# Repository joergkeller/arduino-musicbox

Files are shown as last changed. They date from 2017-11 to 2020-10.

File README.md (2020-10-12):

# Arduino MusicBox

Arduino control code for a music maker board and a trellis keypad with optional nfc reader.

Hardware parts:
* Adafruit Feather 32u4 Basic Proto
* Adafruit FeatherWing MusicMaker
* Adafruit Trellis PCB, Elastomer, LED
* PN532 NFC reader
* Amplifier, Stereo speaker 
* Rotary Decoder
* LiPolymer 3.7V Akku

The control code shall
* animate the trellis keys while idle
* read trellis keys
* on key press play a music track from the micro SD card from a configured folder and blink the respective key
* on pressing the same key or when playback stops jump to the next track in the folder, until all music is played
* read the rotary decoder to change the volume, the maximum volume can be configured
* press the rotary decoder to pause/resume (short) and stop/sleep (long)
* detect when a headphone is plugged in and mute the amplifier for the internal speakers
* read nfc chips and play the configured track or album for the given id
* switch the music box  off automatically after an idle period

## Checkout this code
```
git clone https://github.com/joergkeller/arduino-musicbox.git
cd arduino-musicbox
git submodule init
git submodule update
```

## Remarks on the hardware
* See [wiring schema](extras/schema/MusicBox_Schaltplan.pdf)
* Cut the "RESET" bridge on the Adafruit MusicMaker FeatherWing (otherwise a reset of the mp3 chip will also 
  reset the arduino board).
* Set dip switches on the NFC board to use I2C (1: ON, 2: OFF)

## Prepare micro SD card
Copy \<musicbox\>/extras/config/*.cfg in root directory of the SD card.\
Copy music files to the SD card, using 8.3 filenames without special characters.
Assign paths to buttons in buttons.cfg and NFC ids in nfc.cfg.\
Paths can be a folder (all tracks will be played) or a specific story/song. Music files can be in subfolders, but
deeply nested structures should be avoided.

## Howto install using Arduino IDE

File > Preferences > Sketchbook locations:\
\<musicbox\> folder containing src, libraries, extra folders

File > Preferences > Additional Boards Manager URLs:\
https://adafruit.github.io/arduino-board-index/package_adafruit_index.json

Tools > Board > Boards Manager\
 Install Adafruit AVR Boards

Restart Arduino IDE\
Open \<musicbox\>/src/src.ino

Tools > Boards\
 Adafruit Feather 32u4

Tools > Ports\
\<USB port connected to the feather board\>

> Verify/Compile\
> Upload

## Howto install using Arduino CLI
```
arduino-cli core update-index
arduino-cli core install arduino:avr@1.8.3
arduino-cli core install adafruit:avr@1.4.13
arduino-cli compile src --fqbn=adafruit:avr:feather32u4
arduino-cli board list
arduino-cli upload src --fqbn=adafruit:avr:feather32u4 --port COM4 --verify --verbose
```

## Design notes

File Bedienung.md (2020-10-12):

# Bedienungsanleitung "Musikwürfel"

## Einschalten 

Der Musikwürfel kann entweder über den USB-micro Anschluss oder über den eingebauten Akku betrieben werden.
Im Akkubetrieb schaltet der Ein-/Ausschalter (nach vorne) das Gerät ein. Mit USB wird das Gerät mit Strom versorgt, sobald das Kabel eingesteckt ist.
Kurz nach dem Einschalten leuchten die 16 Tasten auf der Front in individuellen Farben auf. Das bedeutet, dass das Gerät bereit ist und die Musik ausgewählt werden kann.

Bemerkung: Je nach Konfiguration der Firmware leuchten die Fronttasten konstant, werden langsam auf-/abgeblendet oder wandern als Lauflicht.

## Musik wählen

Mit Druck auf eine der 16 Fronttasten kann das hinterlegte Musikstück bzw. das Album abgespielt werden. Bei einem Album kann durch erneuten Druck auf das nächste Stück gewechselt werden. Solange ein Musikstück spielt, blinkt die entsprechende Taste langsam.
Beim Abspielen eines Stücks kann durch eine beliebige Taste jederzeit auf das neue Album gewechselt werden.
Wenn ein Musikstück fertig ist, wird innerhalb eines Albums automatisch auf das nächste gewechselt. Nach dem letzten Stück eines Albums geht das Gerät in den Grundzustand (alle Tasten leuchten).

Falls einer Taste kein Musikstück/Album hinterlegt ist, geht das Gerät sofort wieder in den Grundzustand (alle Tasten leuchten).

Bemerkung: Innerhalb eines Albums kann nur vorwärts "geblättert" werden. Um wieder an den Anfang zu gelangen, muss man sich durch das ganze Album drücken, oder besser das Abspielen durch langes Drücken auf den Drehregler beenden und das Album erneut auswählen.

### Musik mit Figur auswählen

In der Konfiguration des Gerätes können NFC-Ids mit einem Musikstück bzw. Album verknüpft werden. Wenn eine Figur oder ein anderer Gegenstand mit einem entsprechenden NFC-Tag auf den Deckel des Musikwürfels gelegt wird, wird das entsprechende Stück abgespielt.

Bemerkung: Beim Abspielen eines Stücks über diese Funktion blinkt immer die erste Fronttaste. Bei einem Album kann mit der ersten Taste auf das nächste Musikstück gewechselt werden.

## Abspielen pausieren oder abbrechen

Durch kurzen Druck auf den Drehregler wird das aktuelle Stück pausiert. Das wird durch langsameres Blinken der aktuellen Fronttaste dargestellt. Ausserdem blinkt der Drehregler blau. Erneutes Drücken des Drehreglers spielt das Musikstück weiter ab.

Durch langer Druck auf den Drehregler (ca. 1 sek) wird das aktuelle Stück abgebrochen und das Gerät geht zurück in den Grundzustand (alle Tasten leuchten).

Bemerkung: Der Pausenzustand hat immer noch einen erhöhten Stromverbrauch, da der Musikdecoder immer läuft und das Musikstück geladen ist. Deshalb wird nach einer konfigurierbaren Zeit (aktuell 60 min) das Gerät in den Standby-Modus gesetzt, worauf eine Fortsetzung des Stücks nicht mehr möglich ist.

## Lautstärke regeln

Mit dem Drehregler kann die Lautstärke geregelt werden. Minimale und maximale Lautstärke können für Lautsprecher- und Kopfhörerbetrieb getrennt in der Konfiguration festgelegt werden.

Bemerkung: Wenn das Gerät ausgeschaltet oder in den Standby-Modus geht, wird die Lautstärke auf den initialen Wert zurückgesetzt.

## Gerät in Standby-Modus setzen

Im Grundmodus (alle Tasten leuchten) kann das Gerät durch langes Drücken (ca. 1 sek) auf den Drehregler in den Standby-Modus gesetzt werden. Nach einiger Zeit im Grundmodus (aktuell 15 min) schaltet sich das Gerät automatisch in den Standby-Modus. Hier werden alle Funktionen abgestellt und der Stromverbrauch wird reduziert. Im Standbymodus blinkt der Drehregler ca. alle 8 sek.

Das Abspielen eines Musikstücks wird ebenfalls durch langes Drücken (ca. 1 sek) gestoppt. Um nicht versehentlich die Funktion zu aktivieren, muss der Drehregler dann losgelassen und erneut lang gedrückt werden um in den Standby-Modus zu gelangen.

Durch Drücken einer beliebigen Fronttaste wird das Gerät wieder aktiviert und gelangt in den Grundmodus (alle Tasten leuchten). Dabei ist aber noch kein Album/Stück ausgewählt, dazu muss erneut eine der Fronttasten gedrückt werden.

## Akku aufladen

Um den Akku aufzuladen, muss das Gerät über einen USB-micro Anschluss mit Strom versorgt werden. *Achtung: Der Akku wird nur geladen, wenn das Gerät mit dem Hauptschalter eingeschalten ist!*

Es muss ein USB-micro Stecker mit einer langen Zunge verwendet werden um einen sicheren Kontakt zu gewährleisten.

Bemerkung: Der Ladestrom ist auf 100 mA begrenzt. Für einen grossen Akku (z.B. 2500 mAh) muss deshalb mit einer langen Ladezeit von z.B. 25 Std gerechnet werden.

## Musikstücke ablegen und verknüpfen

Dazu muss die MicroSD-Karte entnommen werden: Deckel auf der Rückseite entfernen, mit Finger auf die Karte *drücken* um sie zu entriegeln, dann entnehmen.

Die MicroSD kann direkt, über einen SD-Adapter oder ein Zusatzgerät gelesen/geschrieben werden.

- Musikstücke können in einem Verzeichnis als Album zusammengefasst und in beliebigen Unterverzeichnissen abgelegt sein.
- Alben/Musikstücke für die Tasten müssen in der Textdatei ```buttons.cfg``` festgelegt werden. 
- Alben/Musikstücke für Figuren mit NFC-Tags müssen mit ihrer NFC Id in der Textdatei ```nfc.cfg``` festgelegt werden.
- Die physische Reihenfolge der Musikstücke ist entscheidend, nicht die Sortierung nach Namen. Um das sicherzustellen, wird am besten ein Musikstück nach dem andern einzeln auf die SD-Karte geschrieben.
- Beim Einlesen eines neuen NFC-Tags wird die unbekannte Id in die Textdatei ```nfc.cfg``` geschrieben.

Bemerkung: In der aktuellen Version können nur max. 8 Zeichen pro Verzeichnis/Stück angegeben werden. Entweder wird der Name des Stücks auf 8 Zeichen gekürzt oder es wird der Kurzname des längeren Stücks ermittelt (Windows/Cmd mit ```dir /x```). Die Längenbeschränkung gilt auch für einzelne Verzeichnisnamen.

### Beispiel Konfigurationsfiles 
NFC Konfiguration ```nfc.cfg```:
```
6738BC0E=MIGROS/WICHTEL/ELI.MP3
B85D2D35=MIGROS/WICHTEL/FINN.MP3
```

Button Konfiguration ```buttons.cfg```:
```
3=GLOBI/FEUER
4=JAMADU
```

### Unterstützte Audio Decoder Formate

* MP3 CBR+VBR+ABR bis 320 kbps, 48 kHz
* Ogg Vorbis bis 48 kHz, 500 kbps
* AAC VBR, CBR bis 48 kHz, 576 kbps
* WMA (4.0/4.1/7/8/9) bis 48 kHz, 384 kbps
* FLAC bis 48 kHz, 24bit
* WAV (PCM, IMA_ADPCM, MPEGLAYER3)
* MIDI Format 0, max. Polyphonie 64

MP3 sollte ohne die Option 'joint stereo' kodiert werden.

MIDI Instrumente siehe [VS1053 Datenblatt](https://cdn-shop.adafruit.com/datasheets/vs1053.pdf) Seite 32

## Weitere Konfigurationen
- settings.cfg - wird im Moment nicht unterstützt

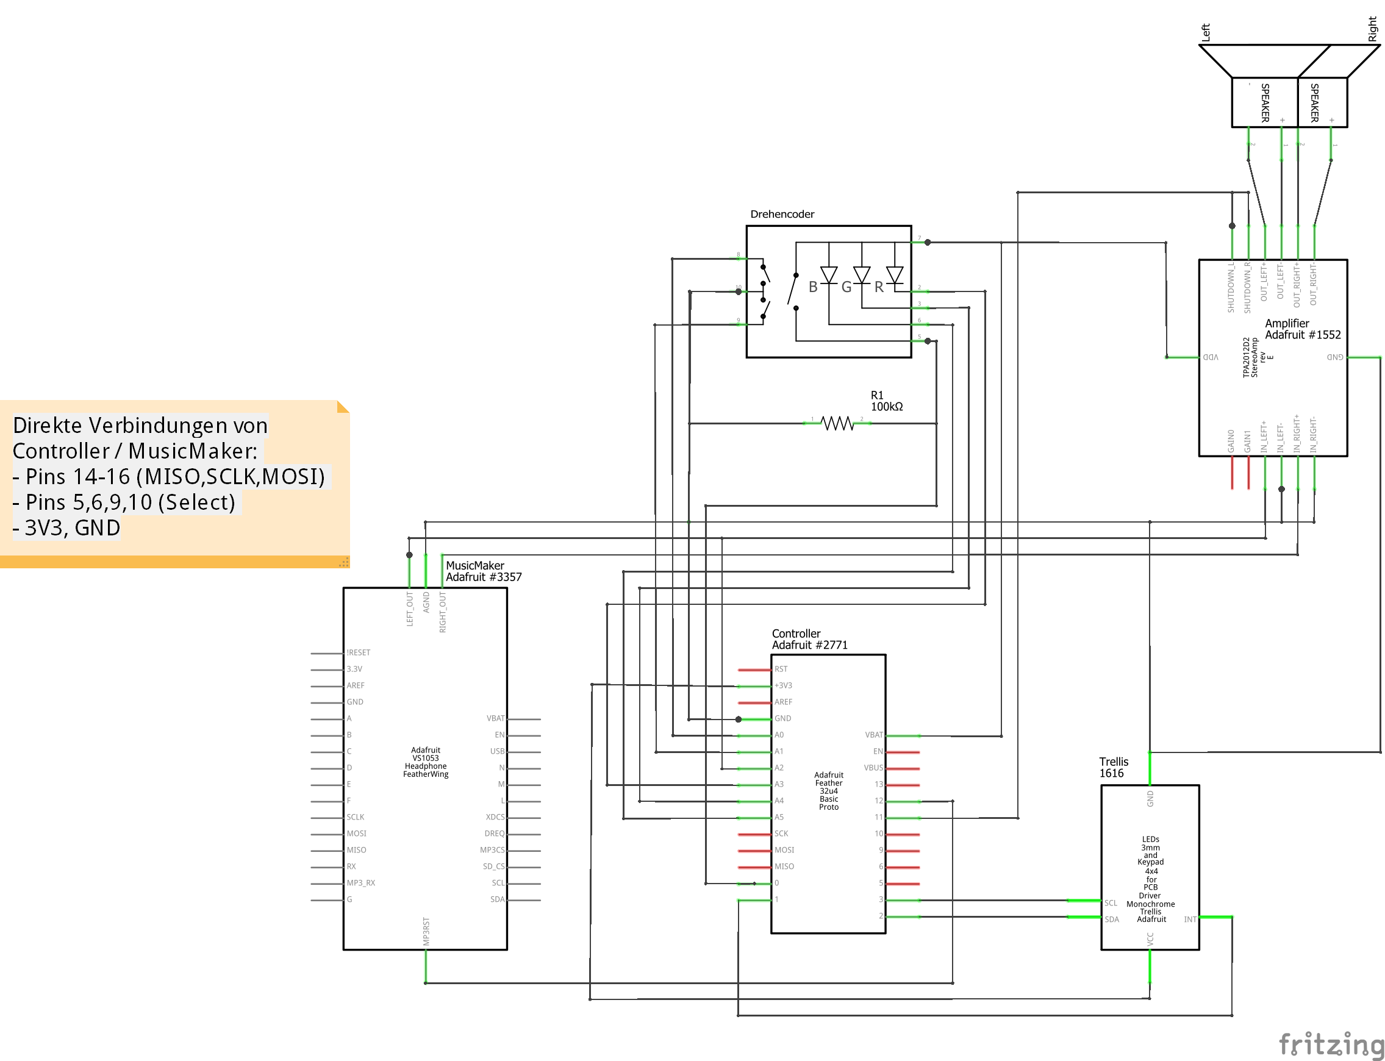
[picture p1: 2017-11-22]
extras/schema/MusicBox_Schaltplan.png

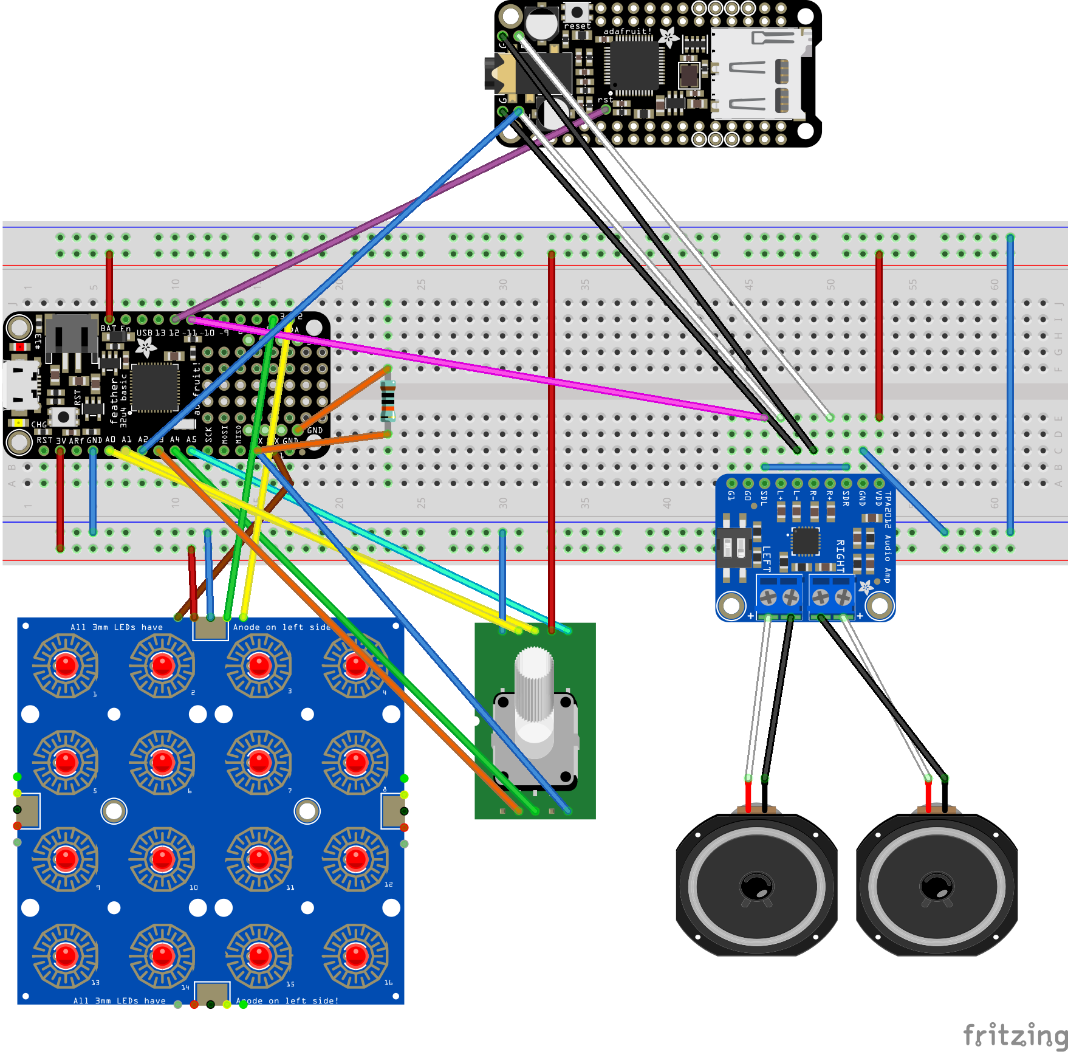
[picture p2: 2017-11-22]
extras/schema/MusicBox_Steckplatine.png

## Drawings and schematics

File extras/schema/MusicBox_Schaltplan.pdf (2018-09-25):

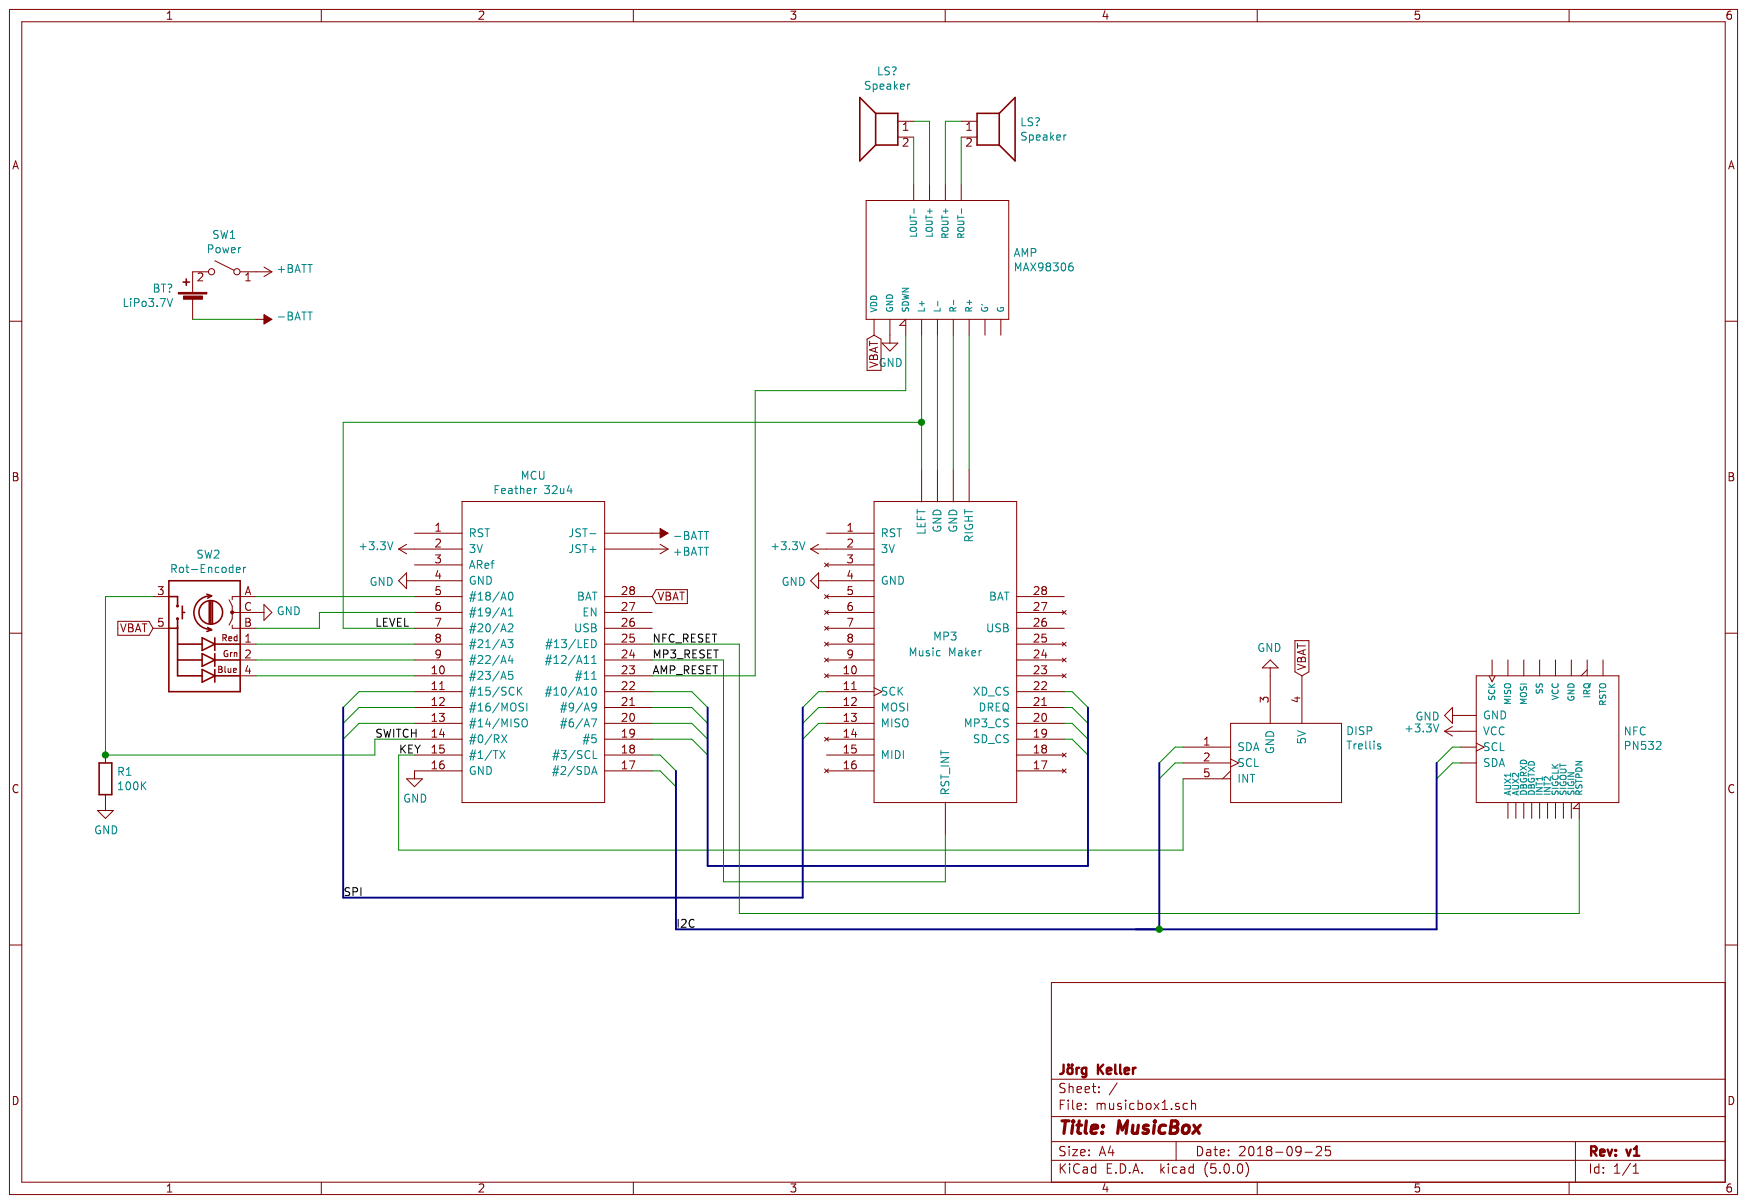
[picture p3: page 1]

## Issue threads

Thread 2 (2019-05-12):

Move ESP32 pins to allow pullup

joergkeller, 2019-05-12:
Not all ESP32 input pins allow INPUT_PULLUP. The encoder switch and the analog level (headphone detection) require the feature, otherwise a physical pullup resistor must be used.

joergkeller, 2019-05-13:
Pin assignment done. Moving some of the RESET signals  and using the RX/TX pins should make it possible.

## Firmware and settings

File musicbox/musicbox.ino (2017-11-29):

/***************************************************
  Arduino control code for a music maker board and a trellis keypad.

  The control code shall
     read trellis keys (/)
     on key press play a music file from the micro SD card from a specific folder and blink the respective key (/)
     on pressing the same key or when playback stops jump to the next file in the folder, until all music is played (/)
     read the rotary decoder to change the volume, the maximum volume can be configured (/)
     press the rotary decoder to pause/resume/stop/sleep (/)
     detect when a headphone is plugged in and mute the amplifier for the internal speakers (/)
     switch the music box off automatically after an idle period

  Todos:
   - Audio off when idle (volume 255,255) -> proper file padding needed (?)

  Written by Jörg Keller, Switzerland
  MIT license, all text above must be included in any redistribution
 ****************************************************/

#include <Wire.h>
#include <SPI.h>
#include <SD.h>
#include <Adafruit_VS1053.h>
#include <Adafruit_Trellis.h>
#include <ClickEncoder.h>
#include <TimerOne.h>
#include <LowPower.h>


// Delays [ms]
#define BLANK_DELAY    2500
#define BLINK_DELAY      20
#define HOLD_DELAY     1500
#define PAUSE_DELAY    1000
#define READ_DELAY       50
#define IDLE_TIMEOUT  (1000L * 60L)
#define PAUSE_TIMEOUT (1000L * 60L *  5L)
#define ROLLOVER_GAP  (1000L * 60L * 60L)

// Trellis LED brightness 1..15
#define BRIGHTNESS_SLEEPTICK  0
#define BRIGHTNESS_IDLE      10
#define BRIGHTNESS_PLAYING   10

// Trellis setup
#define NUMKEYS           16
#define TRELLIS_INT_PIN    1

// Feather/Wing pin setup
#define MUSIC_RESET_PIN   12     // VS1053 reset pin (not used!)
#define CARD_CS_PIN        5     // Card chip select pin
#define MUSIC_CS_PIN       6     // VS1053 chip select pin (output)
#define MUSIC_DCS_PIN     10     // VS1053 Data/command select pin (output)
#define MUSIC_DREQ_PIN     9     // VS1053 Data request, ideally an Interrupt pin (not possible on 32u4)

// Amplifier pin setup
#define AMPLIFIER_ENABLE_PIN   11   // Enable both amplifier channels
#define HEADPHONE_LEVEL_PIN    A2   // Voltage level indicates headphone plugin
#define HEADPHONE_THRESHOLD   100   // Plugged-in: ~20, Unplugged: ~890

// Rotary Encoder with Switch and LED
#define ENCODER_A_PIN       A0
#define ENCODER_B_PIN       A1
#define ENCODER_SWITCH_PIN   0
#define RED_LED_PIN         A3
#define GREEN_LED_PIN       A4
#define BLUE_LED_PIN        A5

// States
#define IDLE_LIGHT_UP   1
#define IDLE_WAIT_ON    2
#define IDLE_TURN_OFF   3
#define IDLE_WAIT_OFF   4
#define PLAY_SELECTED   5
#define PLAY_PAUSED     6
#define TIMEOUT_WAIT    7 

// Volume
#define SPEAKER_VOLUME_MIN         130    // max. 254 moderation
#define SPEAKER_VOLUME_MAX          15    // min. 0 moderation
#define HEADPHONE_VOLUME_MIN       150    // max. 254 moderation
#define HEADPHONE_VOLUME_MAX        60    // min. 0 moderation
#define VOLUME_DIRECTION            +1
#define VOLUME_OFF                 255    // 255 = switch audio off, TODO avoiding cracking noise, maybe correct stuffing needed when stop

/***************************************************
   Variables
 ****************************************************/

Adafruit_Trellis trellis = Adafruit_Trellis();
Adafruit_VS1053_FilePlayer player = Adafruit_VS1053_FilePlayer(MUSIC_RESET_PIN, MUSIC_CS_PIN, MUSIC_DCS_PIN, MUSIC_DREQ_PIN, CARD_CS_PIN);
ClickEncoder encoder = ClickEncoder(ENCODER_A_PIN, ENCODER_B_PIN, ENCODER_SWITCH_PIN, 2, LOW, HIGH);


unsigned long nextReadTick = millis() + 1;
unsigned long nextIdleTick = millis() + 1;
unsigned long nextTimeoutTick = 0;
byte state = IDLE_LIGHT_UP;
byte nextLED = 0;
byte playingAlbum;
File album;
int volume = 35;
boolean headphone = false;
boolean headphoneFirstMeasure = false;


/***************************************************
   Setup
 ****************************************************/
void setup() {
  initializeAmplifier();

  Serial.begin(14400);
  while (!Serial && millis() < nextIdleTick + 2000);
  Serial.println(F("MusicBox setup"));

  initializeCard();
  initializePlayer();
  initializeTrellis();
  initializeTimer();
  initializeSwitchLed();                    

  onEnterIdle(0);
}

void initializeSwitchLed() {
  pinMode(RED_LED_PIN, OUTPUT);
  pinMode(GREEN_LED_PIN, OUTPUT);
  pinMode(BLUE_LED_PIN, OUTPUT);
  digitalWrite(RED_LED_PIN, HIGH);   // LED off
  digitalWrite(GREEN_LED_PIN, HIGH); // LED off
  digitalWrite(BLUE_LED_PIN, HIGH);  // LED off
}

void initializeAmplifier() {
  pinMode(AMPLIFIER_ENABLE_PIN, OUTPUT);
  pinMode(HEADPHONE_LEVEL_PIN, INPUT_PULLUP);
  enableAmplifier(false);
}

void initializeCard() {
  if (!SD.begin(CARD_CS_PIN)) {
    Serial.println(F("SD failed, or not present"));
    while (1);  // don't do anything more
  }
  Serial.println(F("SD initialized"));

  File root = SD.open(F("/"));
  while (true) {
    File entry = root.openNextFile();
    if (!entry) break;
    Serial.print(entry.name());
    if (entry.isDirectory()) {
      Serial.println(F("/"));
    } else {
      Serial.print(F("\t\t"));
      Serial.println(entry.size(), DEC);
    }
    entry.close();
  }
  root.close();
}

void initializePlayer() {
  pinMode(MUSIC_RESET_PIN, OUTPUT);
  if (!player.begin()) {
    Serial.println(F("Couldn't find VS1053"));
    while (1);
  }
  player.softReset();
  //player.sineTest(0x44, 500);    // Make a tone to indicate VS1053 is working

  // Timer interrupts are not suggested, better to use DREQ interrupt!
  // but we don't have them on the 32u4 feather...
  player.useInterrupt(VS1053_FILEPLAYER_TIMER0_INT); // timer int
  Serial.println(F("VS1053 initialized"));

  enablePlayer(false);
}

void initializeTrellis() {
  // INT pin requires a pullup;
  // this is also the MIDI Tx pin recommended to bound to high
  pinMode(TRELLIS_INT_PIN, INPUT_PULLUP);

  trellis.begin(0x70);
  //trellis.readSwitches(); // ignore already pressed switches
  Serial.println(F("Trellis initialized"));
}

void initializeTimer() {
  Timer1.initialize(1000);
  Timer1.attachInterrupt(timerIsr);
  Serial.println(F("Timer initialized"));
}

void onEnterIdle(unsigned int delay) {
  trellis.setBrightness(BRIGHTNESS_IDLE);
  trellis.blinkRate(HT16K33_BLINK_OFF);
  trellis.clear();
  trellis.writeDisplay();

  nextReadTick = millis() + 1;
  nextIdleTick = millis() + 1 + delay;
  nextTimeoutTick = millis() + IDLE_TIMEOUT;

  state = IDLE_LIGHT_UP;
  nextLED = 0;
}


/***************************************************
   Interrupt-Handler
 ****************************************************/
void timerIsr() {
  encoder.service();
}

/***************************************************
   Loop
 ****************************************************/
void loop() {
  unsigned long now = millis();

  // Rollover millis since start
  if (nextReadTick > now + ROLLOVER_GAP) {
    Serial.println(F("Rollover timer ticks!"));
    nextReadTick = now + 1;
    nextIdleTick = now + 1;
    nextTimeoutTick = nextTimeoutTick == 0 ? 0 : now + IDLE_TIMEOUT;
  }

  // Next ticks
  if (0 < nextTimeoutTick && nextTimeoutTick <= now) {
    tickIdleTimeout();
  }
  if (0 < nextReadTick && nextReadTick <= now) {
    nextReadTick = now + tickReadKeys();
  }
  if (0 < nextIdleTick && nextIdleTick <= now) {
    nextIdleTick = now + tickIdleShow();
  }

  // Check for finished track
  if (state == PLAY_SELECTED) {
    if (player.stopped()) onTryNextTrack();
  }
}

unsigned long tickIdleShow() {
  // Light up all keys in order
  if (state == IDLE_LIGHT_UP) {
    trellis.setLED(nextLED);
    trellis.writeDisplay();
    nextLED = (nextLED + 1) % NUMKEYS;
    if (nextLED == 0) {
      state = IDLE_WAIT_ON;
    }
    return BLINK_DELAY;

  // Wait with all keys lighted
  } else if (state == IDLE_WAIT_ON) {
    state = IDLE_TURN_OFF;
    return HOLD_DELAY;

  // Turn off all keys in order
  } else if (state == IDLE_TURN_OFF) {
    trellis.clrLED(nextLED);
    trellis.writeDisplay();
    nextLED = (nextLED + 1) % NUMKEYS;
    if (nextLED == 0) {
      state = IDLE_WAIT_OFF;
      return BLANK_DELAY;
    }
    return BLINK_DELAY;

  // Wait in darkness
  } else if (state == IDLE_WAIT_OFF) {
    trellis.clear(); // just to clean up
    trellis.writeDisplay();
    state = IDLE_LIGHT_UP;
    return BLINK_DELAY;

  // Blink in pause mode
  } else if (state == PLAY_PAUSED) {
    blinkLED(BLUE_LED_PIN);
    return PAUSE_DELAY;
  }
}

void tickIdleTimeout() {
  Serial.println(F("Timeout!"));
  onTimeout();

  attachInterrupt(digitalPinToInterrupt(TRELLIS_INT_PIN), trellisIsr, LOW);
  LowPower.powerDown(SLEEP_8S, ADC_OFF, BOD_OFF); 

  if (state == TIMEOUT_WAIT) {
    // temporary wakeup after 8s, no interrupt called
    onWatchdogPing();
  } else {
    onSleepWake();
  }
}

void onTimeout() {
  trellis.clear();
  trellis.writeDisplay();
  trellis.sleep();
  
  state = TIMEOUT_WAIT;
}

void onWatchdogPing() {
  blinkLED(BLUE_LED_PIN);
}

void blinkLED(int pin) {
  digitalWrite(pin, LOW); // LED on
  delay(1);
  digitalWrite(pin, HIGH); // LED off
}

void trellisIsr() {
  detachInterrupt(digitalPinToInterrupt(TRELLIS_INT_PIN));
  state = IDLE_LIGHT_UP;
}

void onSleepWake() {
  trellis.wakeup();
  waitForNoKeyPressed();
  onEnterIdle(0);
}

void waitForNoKeyPressed() {
  unsigned long timeout = millis() + 1000;
  while (millis() <= timeout) { 
    byte keyPressed = 0;
    trellis.readSwitches();
    for (byte i = 0; i < NUMKEYS; i++) {
      keyPressed += trellis.isKeyPressed(i) ? 1 : 0;
    }
    if (keyPressed == 0) return;
    delay(20);
  }
}

unsigned long tickReadKeys() {
  // Read trellis keys
  if (trellis.readSwitches()) {
    for (byte i = 0; i < NUMKEYS; i++) {
      if (trellis.justPressed(i)) {
        if (state == TIMEOUT_WAIT) onSleepWake();
        onKey(i);
        break;
      }
    }
  }

  // Read encoder position
  if (state == PLAY_SELECTED) {
    int encoderChange = encoder.getValue() * VOLUME_DIRECTION;
    if (encoderChange != 0) {
      changeVolume(encoderChange);
    }
  }

  // Read encoder switch
  static bool consumedHeld = false;
  ClickEncoder::Button button = encoder.getButton();
  if (button == ClickEncoder::Clicked) {
    switch (state) {
      case PLAY_SELECTED: onPause(true); break;
      case PLAY_PAUSED:   onPause(false); break;
    }
  } else if (button == ClickEncoder::Held && !consumedHeld) {
    consumedHeld = true;
    switch (state) {
      case PLAY_SELECTED:
      case PLAY_PAUSED:
        Serial.print(F("Stopped #")); Serial.println(playingAlbum);
        blinkLED(BLUE_LED_PIN);
        stopPlaying();
        onStopPlaying();
      break;

      case IDLE_LIGHT_UP:
      case IDLE_TURN_OFF:
      case IDLE_WAIT_OFF:
        Serial.println(F("Force timeout"));
        blinkLED(BLUE_LED_PIN);
        delay(300);
        blinkLED(BLUE_LED_PIN);
        nextTimeoutTick = millis();
      break;
    }
  } else if (button == ClickEncoder::Released) {
    consumedHeld = false;
  }

  // Read headphone level
  int audioLevel = analogRead(HEADPHONE_LEVEL_PIN);
  if (headphone != headphoneFirstMeasure && (audioLevel > HEADPHONE_THRESHOLD) != headphoneFirstMeasure) {
    // confirmed change
    onHeadphoneInserted(audioLevel < HEADPHONE_THRESHOLD);
    Serial.print(F("Confirmed change, headphone ")); Serial.println(headphoneFirstMeasure);
  } else if ((audioLevel < HEADPHONE_THRESHOLD) != headphoneFirstMeasure) {
    // there seems to be a change
    headphoneFirstMeasure = (audioLevel < HEADPHONE_THRESHOLD);
    Serial.print(F("Possible change, headphone ")); Serial.println(headphoneFirstMeasure);
  }

  return READ_DELAY;
}

void onKey(byte index) {
  // No keys when paused
  if (state == PLAY_PAUSED) {
    // nop
    Serial.println(F("Still paused"));

  // Same key pressed again
  } else if (state == PLAY_SELECTED && playingAlbum == index) {
    nextTimeoutTick = 0; // no timeout during playing
    stopPlaying();
    onTryNextTrack();

  // Some (other) key pressed
  } else {
    if (state == PLAY_SELECTED) stopPlaying();
    nextTimeoutTick = 0; // no timeout during playing
    enablePlayer(true);
    enableAmplifier(!headphone);
    onStartFirstTrack(index);
  }
}

void onStartFirstTrack(byte index) {
  playingAlbum = index;
  blinkSelected(playingAlbum);
  openNewAlbum(playingAlbum);
  if (playNextTrack()) {
    Serial.print(F("Playing album #")); Serial.println(playingAlbum);
    state = PLAY_SELECTED;
  } else {
    Serial.print(F("Failed album #")); Serial.println(playingAlbum);
    onStopPlaying();
  }
}

void onTryNextTrack() {
  if (playNextTrack()) {
    Serial.print(F("Playing next track album #")); Serial.println(playingAlbum);
    blinkSelected(playingAlbum);
    state = PLAY_SELECTED;
  } else {
    Serial.print(F("Ended album #")); Serial.println(playingAlbum);
    onStopPlaying();
  }
}

void onPause(bool pause) {
  if (pause) {
    Serial.println(F("Pause"));
    trellis.blinkRate(HT16K33_BLINK_HALFHZ);
    player.pausePlaying(true);
    enableAmplifier(false);
    nextTimeoutTick = millis() + PAUSE_TIMEOUT;
    state = PLAY_PAUSED;
  } else {
    Serial.println(F("Resume"));
    trellis.blinkRate(HT16K33_BLINK_1HZ);
    enableAmplifier(!headphone);
    player.pausePlaying(false);
    nextTimeoutTick = 0; // no timeout during playing
    state = PLAY_SELECTED;
  }
}

void onStopPlaying() {
  enableAmplifier(false);
  enablePlayer(false);
  if (album && album.isDirectory()) album.close();
  onEnterIdle(1200);
}

void onHeadphoneInserted(boolean plugged) {
  headphone = plugged;
  if (plugged) {
    volume = volume + HEADPHONE_VOLUME_MAX - SPEAKER_VOLUME_MAX;
  } else {
    volume = volume + SPEAKER_VOLUME_MAX - HEADPHONE_VOLUME_MAX;
  }
  enableAmplifier(!headphone);
}

// Set volume for left, right channels. lower numbers == louder volume!
//   0: max volume
//  20: cracks on amplified loudspeaker
// 130: audible
// 254: min volume
// 255: analog off
void changeVolume(int encoderChange) {
  volume += encoderChange;
  if (headphone) {
    volume = max(HEADPHONE_VOLUME_MAX, min(volume, HEADPHONE_VOLUME_MIN));
  } else {
    volume = max(SPEAKER_VOLUME_MAX, min(volume, SPEAKER_VOLUME_MIN));
  }
  Serial.print(F("Set Volume ")); Serial.println(volume);
  player.setVolume(volume, volume);
}

void blinkSelected(byte index) {
  trellis.clear();
  trellis.setBrightness(BRIGHTNESS_PLAYING);
  trellis.setLED(index);
  trellis.blinkRate(HT16K33_BLINK_1HZ);
  trellis.writeDisplay();
}

boolean openNewAlbum(byte index) {
  int albumNr = index + 1;
  String albumTemplate = F("ALBUM");
  String albumName = albumTemplate + albumNr;
  if (album && album.isDirectory()) album.close();
  album = SD.open(albumName);
}

boolean playNextTrack() {
  if (!album || !album.isDirectory()) return false;
  File track = album.openNextFile();
  if (!track) return false;

  String albumName = album.name();
  String dirPath = albumName + '/';
  String filePath = dirPath + track.name();
  Serial.print(F("Next track: ")); Serial.println(filePath);
  track.close();

  player.startPlayingFile(filePath.c_str());
  return true;
}

void stopPlaying() {
  player.stopPlaying();
  delay(20);
}

void enablePlayer(boolean enable) {
  if (enable) {
    digitalWrite(MUSIC_RESET_PIN, HIGH);
    player.reset();
    player.setVolume(volume, volume);
  } else {
    player.setVolume(VOLUME_OFF, VOLUME_OFF);
    digitalWrite(MUSIC_RESET_PIN, LOW);
  }
}

void enableAmplifier(boolean enable) {
  digitalWrite(AMPLIFIER_ENABLE_PIN, enable);
}

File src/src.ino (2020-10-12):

/***************************************************
  Arduino control code for a music maker board and a trellis keypad with optional nfc reader.

  The control code shall
     animate the trellis keys while idle (/)
     read trellis keys (/)
     on key press play a music file from the micro SD card from a specific folder and blink the respective key (/)
     on pressing the same key or when playback stops jump to the next file in the folder, until all music of that folder is played (/)
     read the rotary decoder to change the volume, the maximum volume can be configured (/)
     press the rotary decoder to pause/resume (short) and stop/sleep (long) (/)
     detect when a headphone is plugged in and mute the amplifier for the internal speakers (/)
     read nfc chips and play the configured file for the given id (/)
     switch the music box off automatically (sleep mode) after an idle period, wake on key press (/)

  Todos:
   - Audio off when idle (volume 255,255) -> proper file padding needed (?)

  Written by Jörg Keller, Switzerland
  https://github.com/joergkeller/arduino-musicbox
  MIT license, all text above must be included in any redistribution
 ****************************************************/

#include <Wire.h>
#include <SPI.h>
#include <SD.h>
#include <ClickEncoder.h>
#include <TimerOne.h>
#include <LowPower.h>
#include <PN532_I2C.h>
#include <PN532.h>
#undef NULL
#include <NfcAdapter.h>
#include <Properties.h>
#include "Matrix.h"
#include "Player.h"


// Delays [ms]
#define PAUSE_DELAY    1000
#define READ_DELAY       50
#define NFC_DELAY      1000
#define IDLE_TIMEOUT  (1000L * 60L * 15L)
#define PAUSE_TIMEOUT (1000L * 60L * 60L)
#define ROLLOVER_GAP  (1000L * 60L * 60L)

// Rotary Encoder with Switch and LED
#define ENCODER_A_PIN       A0
#define ENCODER_B_PIN       A1
#define ENCODER_SWITCH_PIN   0
#define RED_LED_PIN         A3
#define GREEN_LED_PIN       A4
#define BLUE_LED_PIN        A5
#define VOLUME_DIRECTION    -3    // set direction of encoder-volume

// NFC pin setup
#define NFC_RESET_PIN   13    // PN532 reset pin

// States
#define IDLE            1
#define PLAY_SELECTED   2
#define PLAY_PAUSED     3
#define TIMEOUT_WAIT    4 

// NFC reader
#define NFC_RETRIES   0    // 0 = one try, 255 = retry forever

/***************************************************
   Variables
 ****************************************************/
Matrix matrix = Matrix();
Player player = Player();
ClickEncoder encoder = ClickEncoder(ENCODER_A_PIN, ENCODER_B_PIN, ENCODER_SWITCH_PIN, 2, LOW, HIGH);
PN532_I2C pn532i2c(Wire);
PN532 nfc(pn532i2c);


unsigned long nextReadTick = millis() + 1;
unsigned long nextNfcTick = millis() + 1;
unsigned long nextIdleTick = millis() + 1;
unsigned long nextTimeoutTick = 0;
byte state = IDLE;
byte playingAlbum;
bool tickMs = false;


/***************************************************
   Setup
 ****************************************************/
void setup() {
  Serial.begin(19200);
  while (!Serial && millis() < nextIdleTick + 75);
  Serial.println(F("MusicBox setup"));

  matrix.initialize();
  player.initialize();
  initializeSwitchLed();                    
  initializeNfc();
  initializeTimer();

  onEnterIdle(0);
}

void initializeSwitchLed() {
  pinMode(RED_LED_PIN, OUTPUT);
  pinMode(GREEN_LED_PIN, OUTPUT);
  pinMode(BLUE_LED_PIN, OUTPUT);
  digitalWrite(RED_LED_PIN, HIGH);   // LED off
  digitalWrite(GREEN_LED_PIN, HIGH); // LED off
  digitalWrite(BLUE_LED_PIN, HIGH);  // LED off
}

void initializeNfc() {
  pinMode(NFC_RESET_PIN, OUTPUT);
  digitalWrite(NFC_RESET_PIN, HIGH);
  nfc.begin();
  uint32_t versiondata = nfc.getFirmwareVersion();
  if (!versiondata) {
    Serial.println(F("PN532 failed"));
    return;
  }

  // Set the max number of retry attempts to read from a card.
  // This prevents us from waiting forever for a card, which is the default behaviour of the PN532.
  nfc.setPassiveActivationRetries(NFC_RETRIES);
  nfc.SAMConfig();  
  Serial.println(F("PN532 initialized"));
}

void initializeTimer() {
  Timer1.initialize(1000);
  Timer1.attachInterrupt(timerIsr);
  Serial.println(F("Timer initialized"));
}

void onEnterIdle(unsigned int delay) {
  state = IDLE;
  matrix.idle();
  enableNfc(true);

  nextReadTick = millis() + 1;
  nextNfcTick = millis() + 1;
  nextIdleTick = millis() + 1 + delay;
  nextTimeoutTick = millis() + IDLE_TIMEOUT;
}


/***************************************************
   Interrupt-Handler
 ****************************************************/
void timerIsr() {
  encoder.service();
  tickMs = true;
}

void trellisIsr() {
  matrix.disableInterrupt();
  state = IDLE;
}

/***************************************************
   Loop
 ****************************************************/
void loop() {
  unsigned long now = millis();

  // Rollover millis since start
  if (nextReadTick > now + ROLLOVER_GAP) {
    Serial.println(F("Rollover timer ticks!"));
    nextReadTick = now + 1;
    nextIdleTick = now + 1;
    nextTimeoutTick = nextTimeoutTick == 0 ? 0 : now + IDLE_TIMEOUT;
  }

  // Next ticks (timeout check first to go back to sleep mode after blink)
  if (0 < nextTimeoutTick && nextTimeoutTick <= now) {
    tickIdleTimeout(now);
  }
  if (0 < nextReadTick && nextReadTick <= now) {
    tickReadKeys(now);
  }
  if (0 < nextNfcTick && nextNfcTick <= now) {
    tickReadNfc(now);
  }
  if (0 < nextIdleTick && nextIdleTick <= now) {
    tickIdleShow(now);
  }
  if (tickMs) {
    matrix.tickMs();
    tickMs = false;
  }

  // Check for finished track
  if (state == PLAY_SELECTED) {
    if (player.hasStopped()) onTryNextTrack();
  }
}

void tickIdleShow(unsigned long now) {
  // Blink in pause mode
  if (state == PLAY_PAUSED) {
    blinkLED(BLUE_LED_PIN);
    nextIdleTick = now + PAUSE_DELAY;
  }
}

void tickIdleTimeout(unsigned long now) {
  Serial.println(F("Timeout!"));
  onTimeout();

  matrix.enableInterrupt(trellisIsr);
  LowPower.powerDown(SLEEP_8S, ADC_OFF, BOD_OFF); 

  if (state == TIMEOUT_WAIT) {
    // temporary wakeup after 8s, no interrupt called
    onWatchdogPing();
  } else {
    onSleepWake();
  }
}

void onTimeout() {
  matrix.sleep();
  enableNfc(false);
  player.enable(false);
  
  state = TIMEOUT_WAIT;
}

void onWatchdogPing() {
  blinkLED(BLUE_LED_PIN);
}

void onSleepWake() {
  matrix.wakeup();
  // ignore wakeup key
  matrix.waitForNoKeyPressed();
  onEnterIdle(0);
}

void blinkLED(int pin) {
  digitalWrite(pin, LOW); // LED on
  delay(1);
  digitalWrite(pin, HIGH); // LED off
}
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

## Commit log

2017-10-04 play/stop specific music track
2017-10-05 no Serial hang on restart, safe millis rollover/reset
    [sketch.ino]
2017-10-23 read encoder and change volume
2017-10-23 bugfix: no hang if Serial is not available
    [sketch.ino]
2017-10-24 detect plugged-in headset to switch amplifier off
2017-10-26 added sleep mode with watchdog timer
2017-11-09 reset mp3 player when not used (sleep mode)
    [musicbox.ino]
2017-11-09 blink switch led between sleep intervals, keep trellis sleeping
2017-11-15 read encoder button for pause, blink encoder (needs forked encoder library)
2017-11-15 long press encoder button stops playing track
2017-11-19 reassigned pins: Audio-Level A2/20, Red-LED A3/21, Encoder-Switch 0
2017-11-19 hold encoder switch in idle mode to sleep
2017-11-21 all led mounted, changed lighting pattern
2017-11-22 added wiring schema
    [MusicBox.fzz]
2017-11-29 bugfix: close file/dir on read card
    [musicbox.ino]
2017-12-23 standard project structure for Atom and Arduino-IDE, stability modifications.
    [MusicBox.fzz]
2017-12-23 read nfc chip an play configured track
2018-01-22 added extras/config files to put on SD card
    [buttons.cfg, nfc.cfg, settings.cfg]
2018-01-31 complemented notes after debugging second device
2018-02-01 reset nfc chip if not used; changed volume direction
    [nfc.cfg]
2018-02-14 correct enable/disable of NFC chip
    [src.ino]
2018-07-17 fixed init nfc; fixed nfc id number formatting
    [src.ino]
2018-07-17 fixed volume on headphone change
    [src.ino]
2018-07-18 configuration settings changed
    [nfc.cfg]
2018-08-02 append unknown nfc tags to config (fixed)
    [src.ino]
2018-08-02 updated nfc tags
    [nfc.cfg]
2018-08-13 extracted Display class for trellis led control
2018-08-13 moved key and interrupt handling to Display class
2018-09-25 added kicad schema
    [MusicBox.fzz]
2019-03-19 bugfix initializing show on idle
    [src.ino]
2019-03-21 using show classes again, class reference does not work
    [nfc memory dump.txt]
2019-03-21 typo filename Micky.mp3
    [nfc.cfg]
2020-10-10 workflow compilation action (#7)
    * register workflow compilation script
    * configuration for arduino-cli
    * also install base arduino:avr platform
    * explicitly install SD library
2020-10-10 #8 NFC tag can start whole album (not only single track)
2020-10-12 #8 albums in nested directories possible
    [buttons.cfg, nfc.cfg]
2020-10-12 #8 button path from config, not hardcoded
    [buttons.cfg, nfc.cfg]
